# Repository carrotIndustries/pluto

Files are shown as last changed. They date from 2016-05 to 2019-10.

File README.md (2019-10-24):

Pluto is a programmable digital watch that re-uses case and LCD 
panel of the Casio® F-91W.  This is the hardware repo, for the 
software side of things, see [pluto-fw](https://github.com/carrotIndustries/pluto-fw).
Looking for pictures? [There you go.](photos/)
You can discuss the project and ask questions on the [EEVblog forum](http://www.eevblog.com/forum/oshw/diy-watch-based-on-the-casio-f-91w/)

# Features
- Displays time in decimal/binary/hexadecimal base
- Multiple alarms
- Multiple countdown timers
- Uses RTTTL ringtones for alarm sound
- Stopwatch
- Compass
- Speedometer (Enter distance, watch measures time and displays speed in km/h)
- Generation of time-based one-time passwords according to RFC 6238 (WIP)
- Menu-driven interface
- Infrared receiver for software updates and TOTP secret transfer (WIP)
- Useless customisation (Key beep frequency, etc.)
- greater than 1 year battery life (estimate based on current consumption)

# Hardware
Pluto replaces the PCB of the Casio F-91W with a custom one containing 
a MSP430FR6972 MCU, a digital magnetometer (compass) and a 38 kHz 
infrared receiver for software updates and communication. Due to 
careful planning and luck, the Pluto PCB perfectly fits inside of the 
F-91W's mounting frame, although it houses many more components.

- [Schematic as PDF](f-91w.pdf)
- [Kitspace page with BOM and links to buy the parts](https://kitspace.org/boards/github.com/carrotIndustries/pluto)
- [BOM](f-91w.bom)
- [Kitspace BOM](1-click-bom.csv)
- [BOM with Mouser and Digikey part numbers](bom_mouser_digikey.txt)

## MCU
The MSP430FR6972 is a low-power 16bit MCU with integrated segment LCD 
controller. It can be programmed and debugged using the two-wire 
SBW interface accessible through holes in the mounting frame. 

## Digital Magnetometer
The MAG3110 compass is connected to the MCU via I²C. To reduce its power 
consumption to zero when not in use, it's powered from GPIO pin. Due to 
layout constraints, the MCU's I²C interface can't be used, so the 
MCU's firmware has to implement a bit-banged I²C master controller.

## Infrared Receiver
The TSOP57338 38kHz IR receiver is powered from GPIO pin as well since 
it doesn't have any power saving modes. Transmitter and firmware 
support are WIP.

## Other components
The backlight LED is connected to two GPIO pins, so that LEDs of either 
orientation can be fitted.
The driving circuit for the buzzer uses an inductor (measured approx. 
10mH) to boost the battery voltage for increased volume.

## PCB
We manufactured the PCB at [elecrow](http://www.elecrow.com). PCB 
thickness has to be 0.6mm for the PCB to fit between battery clip and plastic 
frame. Note that the PCB has "castellated vias" (for contacting the 
button springs) as PCB manufacturers usually surcharge for these. We 
chose to use ENIG (gold) finish since the original PCB is gold-plated 
as well and Casio wouldn't have done so if this wasn't strictly 
necessary. Unfortunately, not all vias are covered with solder mask due 
manufacturing details (in the gerber files, they are), so you'll have 
to insulate the bottom side of the PCB from the battery with sticky 
tape.

# Software
For details on the software, see the software repository at 
[pluto-fw](https://github.com/carrotIndustries/pluto-fw).

# Why?
I used to own an ez430-Chronos watch, but after several years of use, 
the rubber wrist strap disintegrated, so I needed a new programmable watch. 
Pretty much all of the existing DIY watches are impractical for daily 
use because of bulk, being not waterproof or having miserable battery 
life. 

# PAQ (Possibly asked questions)
Q: Why not just use a smartwatch?  
A: Smartwatches have a miserable battery life of one week at best. Some 
even require user interaction to display the time.

Q: Why isn't there some sort of radio interface? (BLE, nRF24L01)  
A: Take look at [this](photos#perfect-fit) picture to get an idea of the space available 
inside of the F-91W frame. The nRF24L01 is 4 mm×4 mm and barely fits, but 
requires external components like balun and antenna. There's no space 
for these. An IR receiver is the same size as the nRF24L01, but doesn't 
require any external components. TI's CC430 MCUs seem like a perfect 
match for pluto as since they combine MCU and radio, but since the radio operates at 
sub-1GHz frequency, the antenna needs to be prohibitively large.

Q: Why is there no accelerometer?  
A: Accelerometers are the most useful when they're permanently active 
for applications like sleep trackers, pedometers or features like 
"shake to do something". Unfortunately, even accelerometers marketed as
"ultralow power" draw approx 30 µA when running, draining the CR2016
coin cell in less than half a year.  So we decided to dedicate the 
available space to a digital compass.

# Credits
Thanks go to [sh-ow](https://github.com/sh-ow) for adding the compass 
and helping to get the board ready for manufacturing.

# Mixed bag
Stuff loosely related to this project

## Reverse Engineering bare glass LCD panels
For basics on bare glass LCD panels and how to drive them,
see application notes from various MCU vendors.

For driving an unknown LCD panel, one needs to know which 
pins connect to the backplanes (COM) and which ones connect to segments 
(SEG). The easiest way to do so is to apply a square to all pins of the 
LCD panel and invert one pin at a time. When few segments light up, 
you've got a SEG pin, when many light up, you've got a COM pin. 
Sometimes apparently independent LCD segments are driven as one segment 
to save SEG pins. 

## Reverse engineering intricate PCB outlines
The F91-W's original PCB has a rather complicated outline that needs to 
be duplicated with high precision, so that the Pluto PCB fits nicely 
within the existing mounting frame.

By desoldering the spring contacting the piezo buzzer, the PCB is 
completely flat on the bottom side, so it can be placed on a flat-bed 
scanner. This eliminates any kind of distortion you'd get by taking a 
photo. The scanned image can then be scaled to match the actual 
dimensions measured with a caliper. There may be unequal scaling in X 
and Y direction due to inaccuracies of the scanner. We've now got a 
pretty accurate digital representation of the PCB that can be used for 
tracing out the outline and registering photos from the top side of 
the PCB to get the position of pads on top side.

Inkscape and GIMP (for correcting camera distortion) work well for 
these tasks. The resulting outline has been exported as a dxf document 
for importing the outline in KiCad.

## Things that didn't work out
The project started off with the intent of re-purposing the the F-91W 
case and LCD. Unfortunately, the LCD panel of the F-91W is rather 
limited since some LCD segments are driven as one segment.

So we went out and took a look at the Casio W800, F-201 and DB-36 
watch. After manufacturing a test jig for the LCD panels of the former 
two, it turned out that people at Casio /really/ like building LCDs 
with 5 backplanes. For some reason, the LCD panels need also to be driven 
with around 5 Vpp to achieve decent contrast. (Best guess: These 
watches are old designs, LCDs weren't that sensitive back then)

To my best knowledge, there's no (non-unobtainium) MCU on the market, 
that can boost a 3 V supply to 5 V for driving and LCDs /and/ can do 
5-mux. The only MCUs meeting the first requirement are from the RL78 
family from Renesas, but they only do 1,2,3,4 and 8-mux. Driving a 5-mux LCD 
with 8-mux waveforms leads to bad contrast. With 3 V and 5-mux, the contrast is 
much worse.

EPSON offers some obscure MCUs that can do both 5-mux and 
5 V LCD drive, but these ones don't have enough segment pins the QFN64 
package.

So we went back to F-91W.

## Measuring current consumption
For plotting current consumption over time, the EnergyTrace feature of 
the MSP430FR4133 LaunchPad has proven to be really useful: 
[energytrace-util](https://github.com/carrotIndustries/energytrace-util)

## Related Projects
Looking for more buttons and a radio? Take a look at [goodwatch](https://github.com/travisgoodspeed/goodwatch/)

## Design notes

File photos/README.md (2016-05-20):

People like photos, so I took some.

#Whole Watch
Pretty boring, looks just like every F-91W, apart from the binary time 
display.  Top vertical segments are hours, bottom vertical segments are 
minutes, horizontal segments are there for locating the bits.

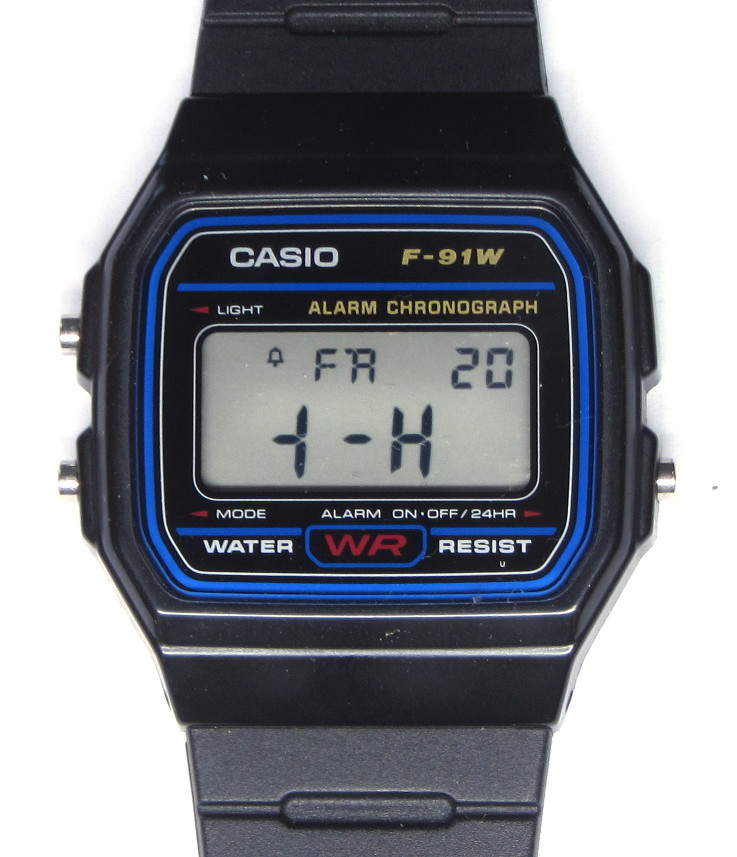
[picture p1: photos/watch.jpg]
Watch


#Frame
The wire sticking out of the bottom left hole is connected to Vcc. It 
has been used to power the watch during firmware development.

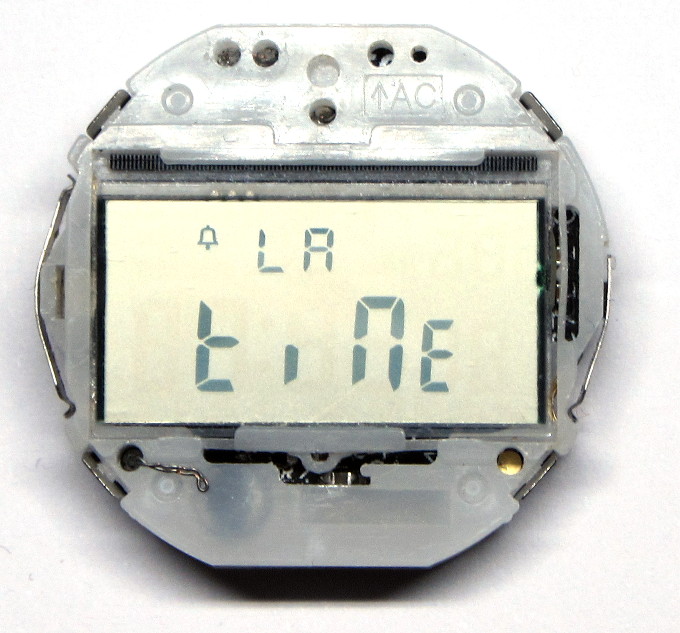
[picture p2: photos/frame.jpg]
Frame


#Populated PCB
Despite of the small-sized components (all passives are 0402),
populating the pluto PCB is doable given a microscope and plenty of 
flux. The inductor at the bottom left as been harvested from the 
original PCB. The crystal is wrapped in sticky tape to avoid shorting C1.

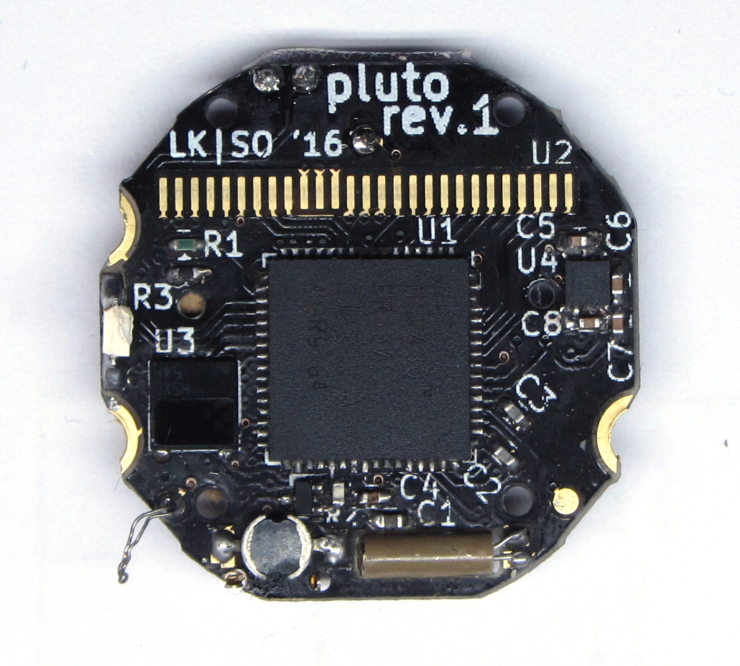
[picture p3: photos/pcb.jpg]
populated pcb


#Perfect fit
Like magic, all components fit perfectly within the plastic frame. 
Little space has been wasted.

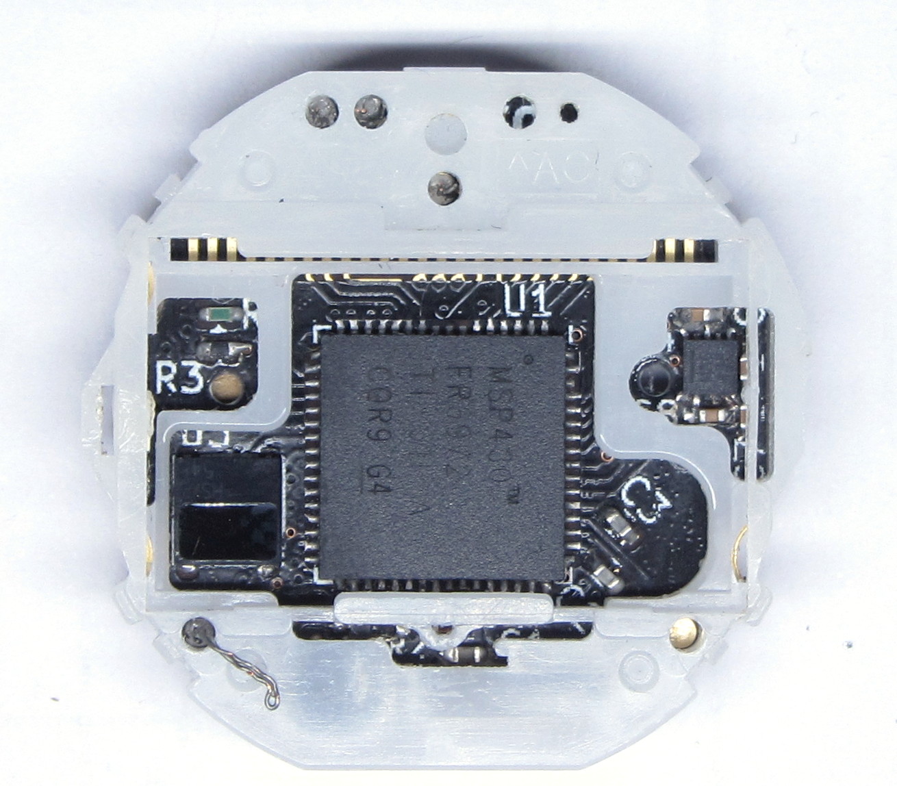
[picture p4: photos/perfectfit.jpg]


#Blank PCB
I case you're curios, there it is:

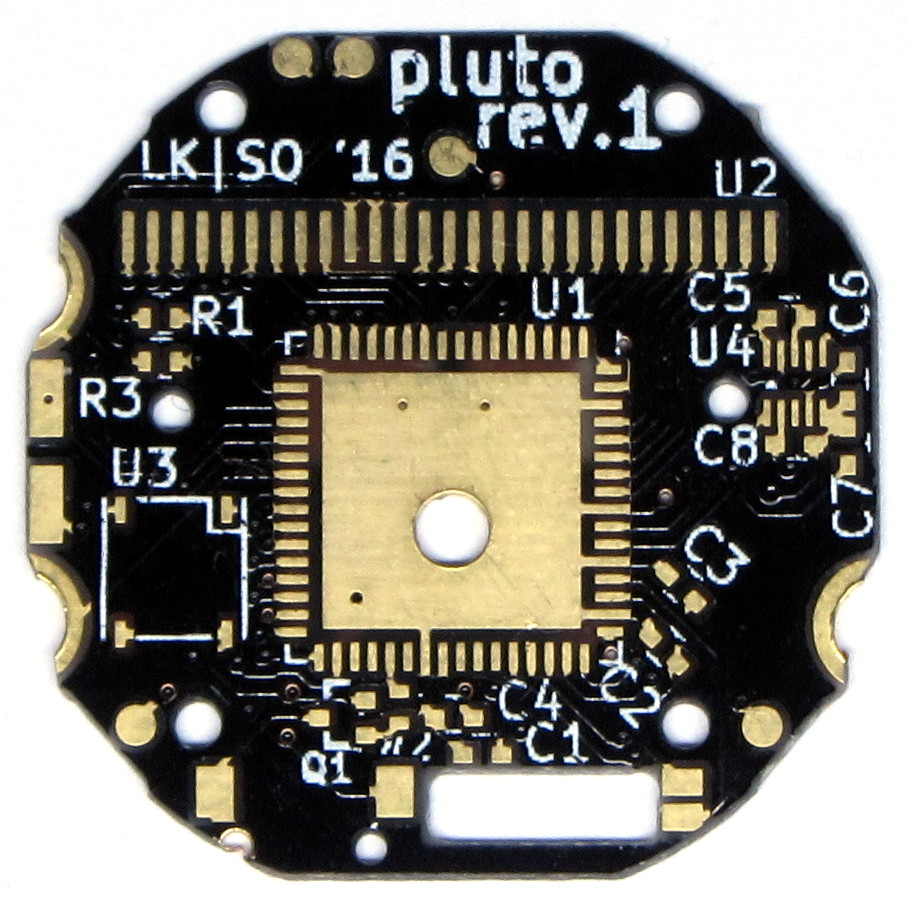
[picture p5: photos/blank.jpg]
blank pcb


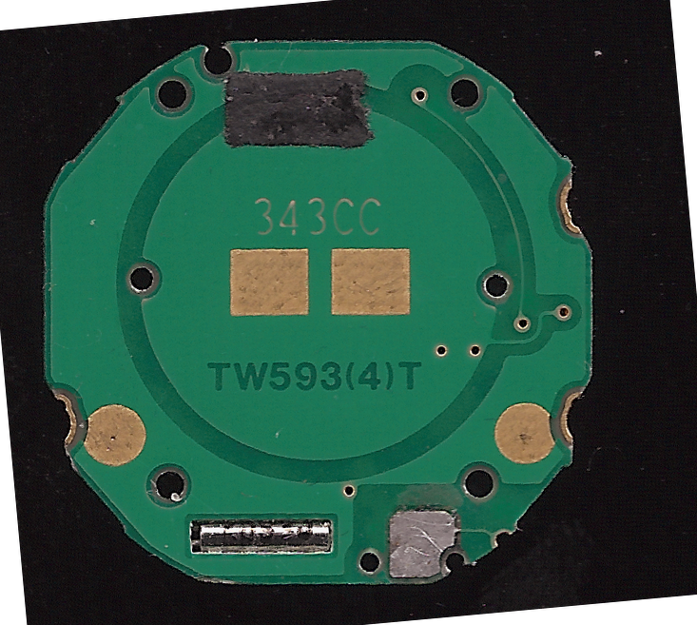
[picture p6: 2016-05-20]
mech/pcb.png

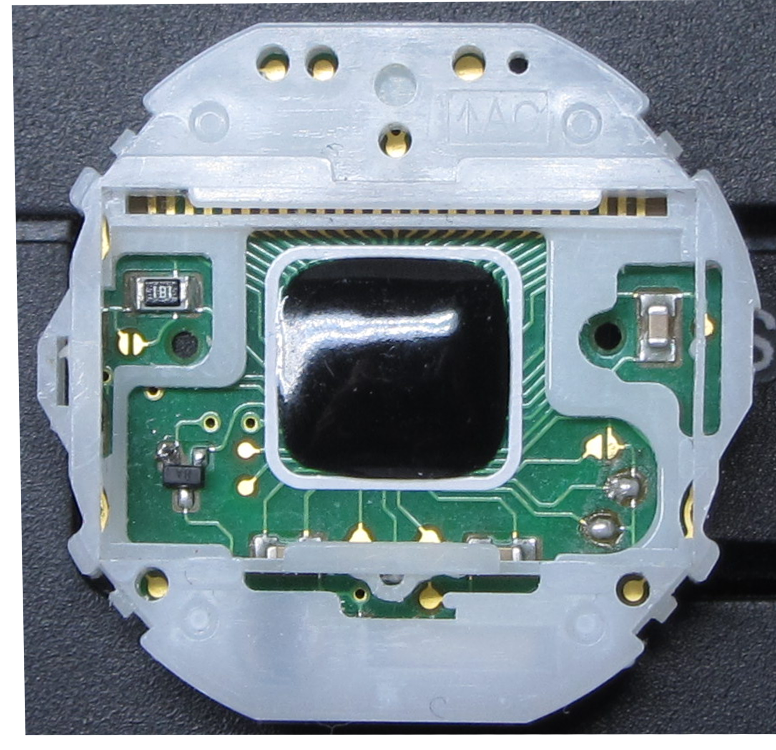
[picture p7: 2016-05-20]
mech/frame.png

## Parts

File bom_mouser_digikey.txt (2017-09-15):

Mouser
--------------------------------------------------------------------------------
QTY  Mouser Part No           MPN                   Description
1    71-CRCW0402100RFKEDH     CRCW0402100RFKEDHP    0402 1/8watt 100ohms 1%
2    810-C1005NP01H120J0A     C1005NP01H120J050BA   0402 12pF 50volts
1    720-LOY876Q2T124Z        LO Y876-Q2T1-24-Z     Orange, 606nm, side view
1    559-NC26-LF              NC26LF-327            32.768 KHz 2X6
5    810-C1005X7R1E104K       C1005X7R1E104K050BB   0402 100nF 10% 25Volts
1    841-MAG3110FCR1          MAG3110FCR1           XYZ DIGITAL SENSOR
1    78-TSOP57438TT1          TSOP57438TT1          IR SENSOR IC 38KHZ
1    594-MCS04020C4702FE0     MCS04020C4702FE000    0402 .063W 47Kohm 1%
1    71-TNPW040210K0DETD      TNPW040210K0DETD      0402 10Kohms .5% 25ppm
1    771-BC846BT115           BC846BT,115           SOT-416-3 TRANS GP TAPE-7
1    810-C1005X5R0J475K       C1005X5R0J475K050BC   0402 4.7uF 6.3volts
1    595-430FR6972IRGCR       MSP430FR6972IRGCR     16-bit Microcontroller (TI)

Digikey
--------------------------------------------------------------------------------
QTY  Digikey Part No          MPN                   Description
1    541-2910-1-ND            RCS0402100RJNED 	    0402 100 OHM 5% 1/5W
2    445-13786-1-ND           C1005NP01H120J050BA   0402 12pF 50volts
1    475-1167-1-ND            LO Y876-R2T1-24-Z     Orange, 606nm, side view
1    631-1205-ND              NC26LF-327            32.768 KHz 2X6
5    445-7348-2-ND            C1005X7R1E104K050BB   0402 100nF 10% 25Volts
1    MAG3110FCR1CT-ND         MAG3110FCR1           XYZ DIGITAL SENSOR
1    TSOP57438TT1CT-ND        TSOP57438TT1          IR SENSOR IC 38KHZ
1    541-47.0KLCT-ND          CRCW040247K0FKED 	 	0402 47K OHM 1% 1/16W
1    541-10.0KLCT-ND          CRCW040210K0FKED      0402 10K OHM 1% 1/16W
1    BC847BTT1GOSCT-ND        BC847BTT1G 	        TRANS NPN 45V 0.1A SC75-3
1    445-5947-1-ND            C1005X5R0J475K050BC   0402 4.7uF 6.3volts
1    296-42269-1-ND           MSP430FR6972IRGCR     16-bit Microcontroller (TI)

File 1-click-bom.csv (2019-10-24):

References | Qty | Description | Manufacturer | MPN | Manufacturer | MPN | Manufacturer | MPN | Digikey | Mouser | RS | Newark | Farnell
Q1 | 1 | SOT416 BC846 | ON Semiconductor | BC847BTT1G |  |  |  |  | BC847BTT1GOSDKR-ND | 863BC847BTT1G | 8009614P |  | 2464041
U2 | 1 | LCD-F-91W
C2, C3 | 2 | Capacitor SMD 0402 22pF | KEMET | C0603C180J5GAC TU. | KEMET | C0603C180J5GACTU | Yageo | CC0402JRNPO9BN220 | 311-1018-6-ND | 603CC402JRNPO9BN220 | 1699965 |  | 3019184
C8, C4, C5, C6, C7 | 5 | Capacitor SMD 0402 100nF | KEMET | C0603C104K5RACTU | TDK | C1005X7R1E104K050BB | Murata | GRM155R71C104KA88D | 490-3261-1-ND | 81GRM155R71C104KA88 | 6242317 |  | 2525045
C1 | 1 | Capacitor SMD 0402 4.7uF | TDK | C1005X5R0J475K050BC |  |  |  |  | 445-5947-1-ND | 810C1005X5R0J475K | 7882821 |  | 2346876
U1 | 1 | 16-bit Microcontroller (TI) | Texas Instruments | MSP430FR6972IRGCR |  |  |  |  | 296-49839-1-ND | 595430FR6972IRGCR
R2 | 1 | Resistor SMD 0402 47k | Yageo | RC0402FR-0747KL |  |  |  |  | 311-47.0KLRDKR-ND | 603RC0402FR0747KL |  |  | 2459293
R1, R3 | 2 | Resistor SMD 0402 10k | Vishay | CRCW040210K0FKED | Panasonic | ERJ-2RKF1002X | Yageo | RC0402FR-0710KL | 311-10.0KLRCT-ND | 603RC0402FR0710KL | 1067096 |  | 2144755
U3 | 1 | TSOP57xxx TSOP57xxx | Vishay | TSOP57438TT1 |  |  |  |  | TSOP57438TT1CT-ND | 78TSOP57438TT1 |  |  | 2251385
U4 | 1 |  | NXP Semiconductors | MAG3110FCR1 |  |  |  |  |  |  |  |  | 2080492

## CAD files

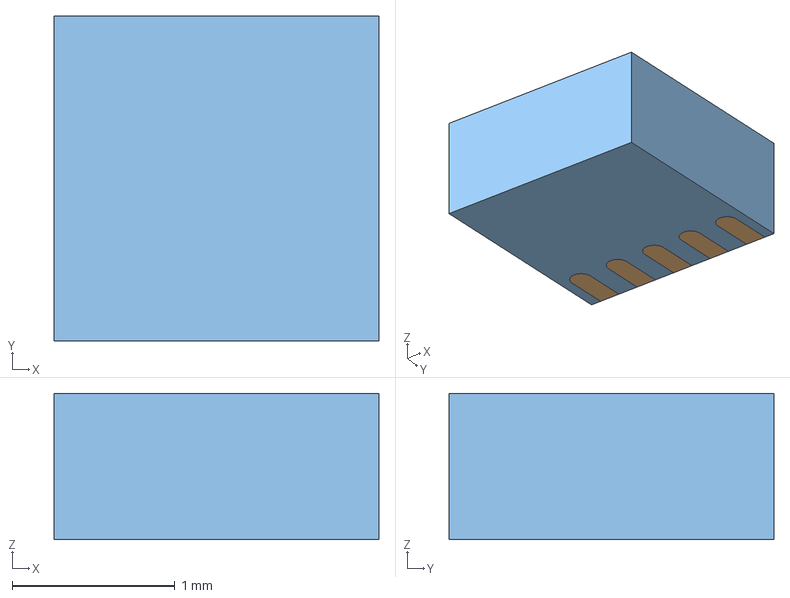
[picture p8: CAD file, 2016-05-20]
10-pin_DFN/10-pin_2x2mm_DFN10.fcstd
2.00 x 2.00 x 0.9 mm
Array (Mirror #1)

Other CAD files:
10-pin_DFN/10-pin_2x2mm_DFN10.obj

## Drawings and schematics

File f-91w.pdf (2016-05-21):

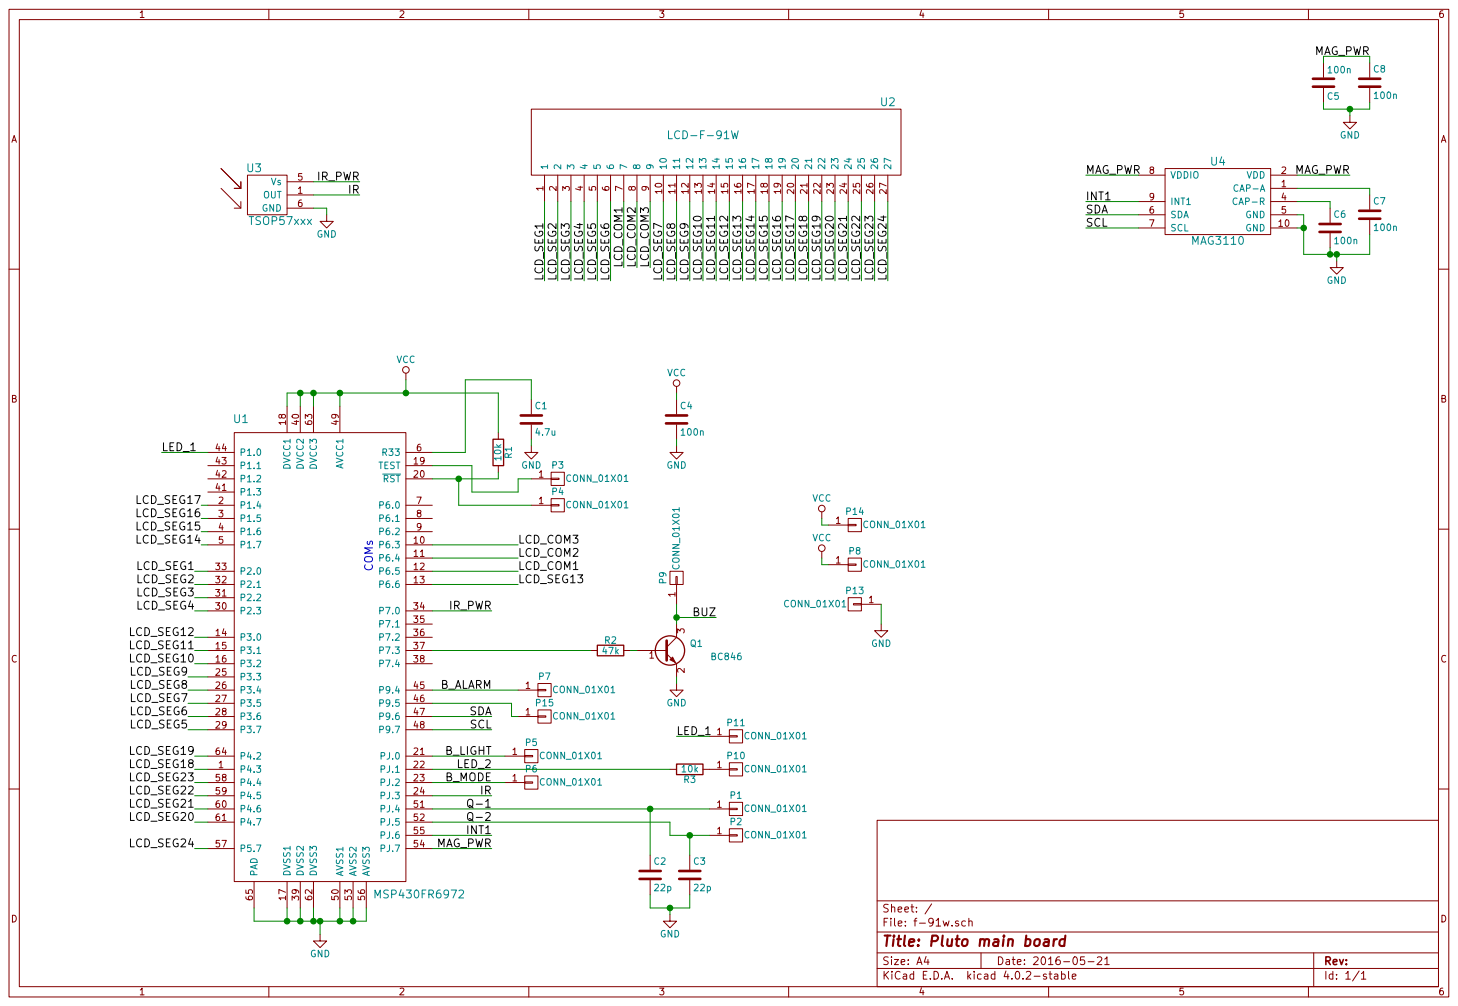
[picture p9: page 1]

INT1 MAG_PWR

Id: 1/1 Title: Pluto main board

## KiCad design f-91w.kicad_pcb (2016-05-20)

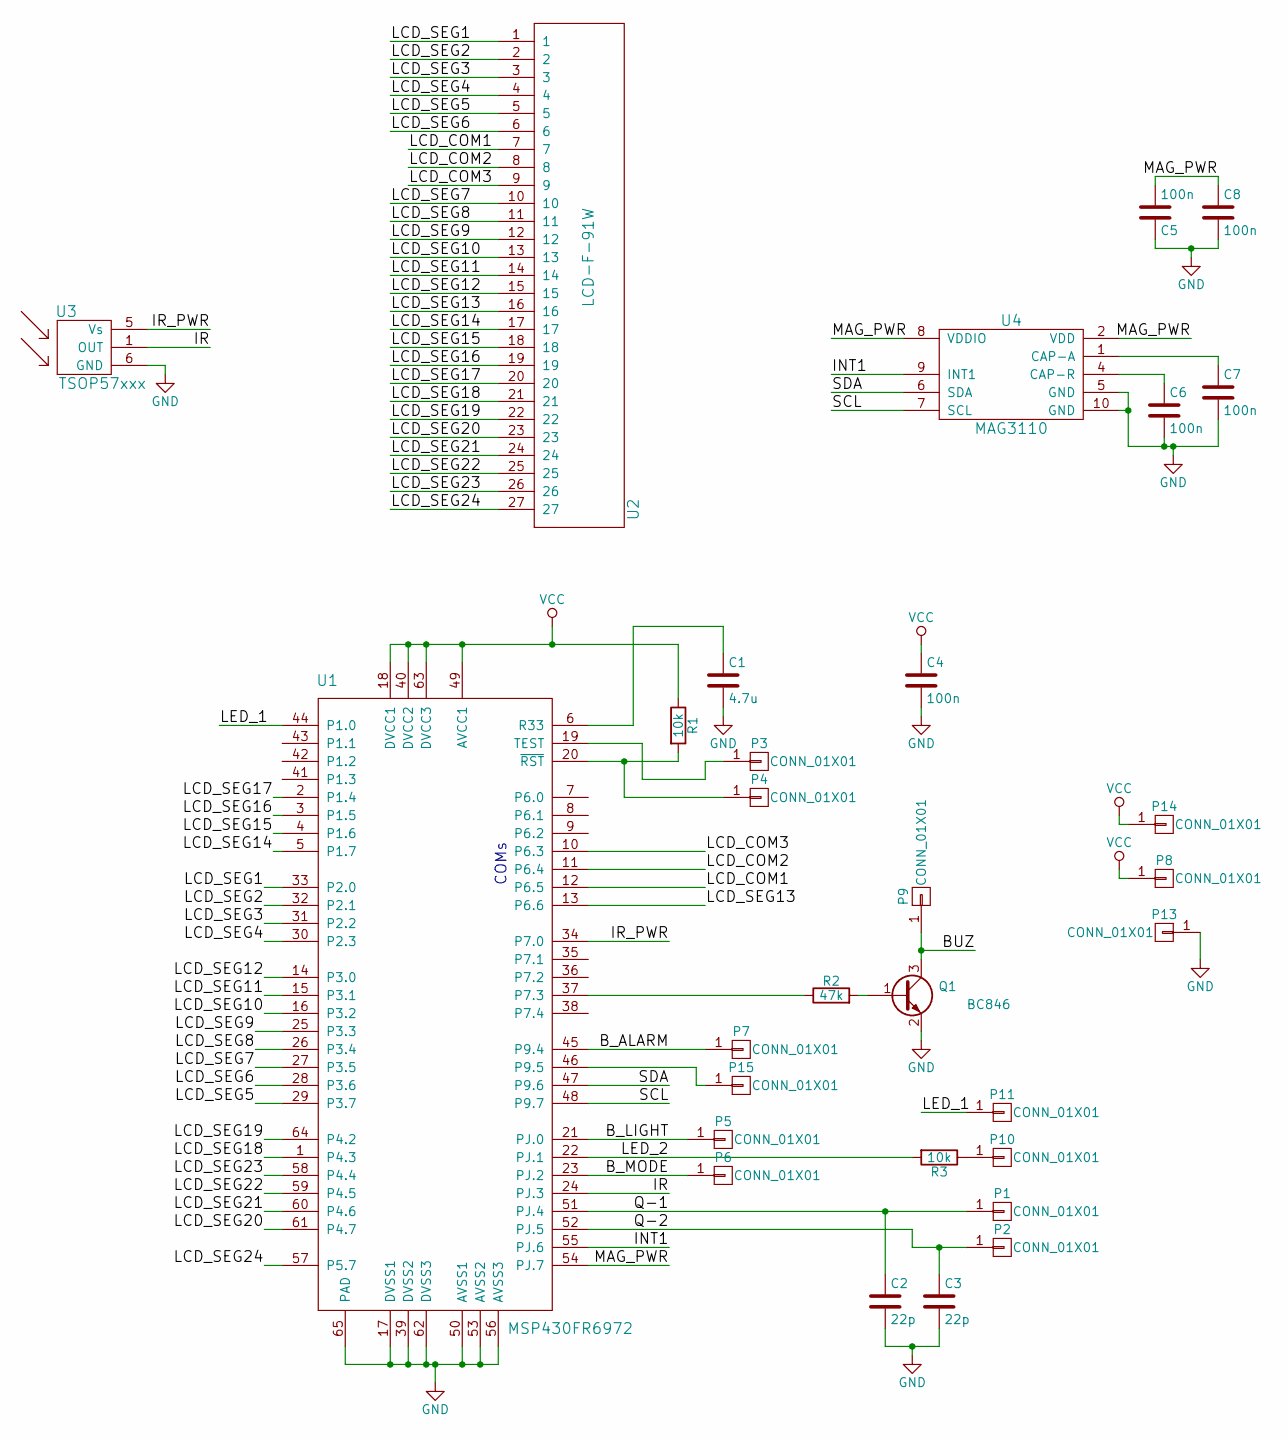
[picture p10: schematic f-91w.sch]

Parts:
C1: 4.7u; C_0402
C2, C3: 22p; C_0402
C4, C5, C6, C7, C8: 100n; C_0402
P1, P2, P3, P4, P5, P6, P7, P8, P9, P10, P11, P13, P14, P15: CONN_01X01; 1pin
Q1: BC846; SOT416
R1, R3: 10k; R_0402
R2: 47k; R_0402
U1: MSP430FR6972; QFN-64-1EP_9x9mm_Pitch0.5mm
U2: LCD-F-91W
U3: TSOP57xxx
U4: MAG3110; DFN-10-1EP_2x2mm_Pitch0.4mm

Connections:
/BUZ: P9.1, Q1.3 (C)
/B_ALARM: P7.1, U1.45 (P9.4)
/B_LIGHT: P5.1, U1.21 (PJ.0)
/B_MODE: P6.1, U1.23 (PJ.2)
/INT1: U1.55 (PJ.6), U4.9 (INT1)
/IR: U1.24 (PJ.3), U3.1 (OUT)
/IR_PWR: U1.34 (P7.0), U3.5 (Vs)
/LCD_COM1: U1.12 (P6.5), U2.7
/LCD_COM2: U1.11 (P6.4), U2.8
/LCD_COM3: U1.10 (P6.3), U2.9
/LCD_SEG1: U1.33 (P2.0), U2.1
/LCD_SEG2: U1.32 (P2.1), U2.2
/LCD_SEG3: U1.31 (P2.2), U2.3
/LCD_SEG4: U1.30 (P2.3), U2.4
/LCD_SEG5: U1.29 (P3.7), U2.5
/LCD_SEG6: U1.28 (P3.6), U2.6
/LCD_SEG7: U1.27 (P3.5), U2.10
/LCD_SEG8: U1.26 (P3.4), U2.11
/LCD_SEG9: U1.25 (P3.3), U2.12
/LCD_SEG10: U1.16 (P3.2), U2.13
/LCD_SEG11: U1.15 (P3.1), U2.14
/LCD_SEG12: U1.14 (P3.0), U2.15
/LCD_SEG13: U1.13 (P6.6), U2.16
/LCD_SEG14: U1.5 (P1.7), U2.17
/LCD_SEG15: U1.4 (P1.6), U2.18
/LCD_SEG16: U1.3 (P1.5), U2.19
/LCD_SEG17: U1.2 (P1.4), U2.20
/LCD_SEG18: U1.1 (P4.3), U2.21
/LCD_SEG19: U1.64 (P4.2), U2.22
/LCD_SEG20: U1.61 (P4.7), U2.23
/LCD_SEG21: U1.60 (P4.6), U2.24
/LCD_SEG22: U1.59 (P4.5), U2.25
/LCD_SEG23: U1.58 (P4.4), U2.26
/LCD_SEG24: U1.57 (P5.7), U2.27
/LED_1: P11.1, U1.44 (P1.0)
/LED_2: R3.2, U1.22 (PJ.1)
/MAG_PWR: C5.2, C8.1, U1.54 (PJ.7), U4.2 (VDD), U4.8 (VDDIO)
/Q-1: C2.1, P1.1, U1.51 (PJ.4)
/Q-2: C3.1, P2.1, U1.52 (PJ.5)
/SCL: U1.48 (P9.7), U4.7 (SCL)
/SDA: U1.47 (P9.6), U4.6 (SDA)
GND: C1.2, C2.2, C3.2, C4.2, C5.1, C6.2, C7.2, C8.2, P13.1, Q1.2 (E), U1.17 (DVSS1), U1.39 (DVSS2), U1.50 (AVSS1), U1.53 (AVSS2), U1.56 (AVSS3), U1.62 (DVSS3), U1.65 (PAD), U3.6 (GND), U4.5 (GND), U4.10 (GND)
unnamed: C1.1, U1.6 (R33)
unnamed: C6.1, U4.4 (CAP-R)
unnamed: C7.1, U4.1 (CAP-A)
unnamed: P3.1, U1.19 (TEST)
unnamed: P4.1, R1.2, U1.20 (~RST)
unnamed: P10.1, R3.1
unnamed: P15.1, U1.46 (P9.5)
unnamed: Q1.1 (B), R2.2
unnamed: R2.1, U1.37 (P7.3)
VCC: C4.1, P8.1, P14.1, R1.1, U1.18 (DVCC1), U1.40 (DVCC2), U1.49 (AVCC1), U1.63 (DVCC3)

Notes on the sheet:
COMs

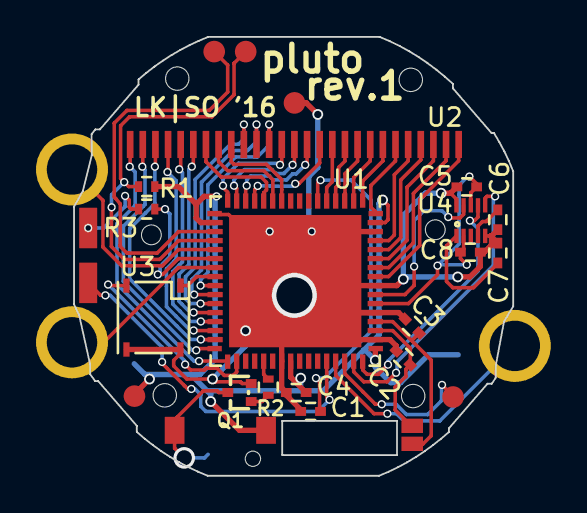
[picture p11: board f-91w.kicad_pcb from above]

Board: 2 copper layers, 24.4 x 24.4 mm, 37 parts (0 on the bottom side), 52 nets.

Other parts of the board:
MH1, MH2, MH3, MH4, MH5, MH6, MH7: 1pin

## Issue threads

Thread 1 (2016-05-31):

buy populated PCBs?

hackrid, 2016-05-31:
Hi,

is there a way to buy populated PCBs ?

BR

luftek, 2017-12-27:
Probably not relevant any more? I did order new batch? #11

vasev01, 2018-10-16:
I’m also interested in buying one populated PCB.

carrotIndustries, 2018-10-18:
Don't hold your breath, but I might to a second board cut in the next few months. Stay tuned!

carrotIndustries, 2018-10-18:
Yeah, that's why I was planning on removing the magnetometer in the next revision. It's been more of a gimmick anyhow.

vasev01, 2019-10-24:
@carrotIndustries A year has passed since you announced a second board in few months. I'm wearing the original casio all the time hoping to be able to program it. Any positive news?

smaslennikov, 2019-10-24:
I, too, am still holding my breath.

carrotIndustries, 2019-10-24:
I'm really sorry, but I'm too busy with other projects to get a new pluto revision out the door.

Anyhow, this project is open source hardware, so feel free to organize make a new rev on your own.

If I'd do it, I'd change these things:
 - Drop compass (EOL and not that useful after all) and IR sensor (no firmware support)
 - Panelize the PCB to drive cost down
 - Make the Vcc capacitor 1µF

If someone really wants to pull this off, I can do design support and review on a best-effort basis.

Good luck!

wannessels, 2019-10-26:
Could you have a look at my [pull request](https://github.com/carrotIndustries/pluto/pull/6)? I'd like to order a batch of boards

tandy-1000, 2020-11-23:
im also interested in this

wannessels, 2020-11-30:
I'll have a go at ordering new PCB's.

Anyone who's interested, can you tell me what and how many you're interested in?
- Bare PCB's
- PCB + components, unsoldered. You will need some sort of MSP430 devkit to flash the mcu
- PCB + components, soldered and flashed. You will still need to desolder and reuse the inductor from a donor F-91W

vasev01, 2020-11-30:
@wannessels, the bare PCB is not a problem nowadays just drop a zip file with gerbers and fill in your address and you are done. However, soldering small SMD components, especially those VQFNs and BGAs, is the problem for many of us.
So, my choice would be PCB with soldered components (at least CPU).

Thanks,
Eugene.

lpasselin, 2020-11-30:
How much would that be total for each popupated PCB including parts?

smaslennikov, 2020-11-30:
Depending on pricing, I'd go for somewhere between two and five populated boards.

tandy-1000, 2020-11-30:
id be interested in one populated board

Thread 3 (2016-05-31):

why no sub-optimal 1 GHz antenna?

hackrid, 2016-05-31:
even if no long distances could be reached, wouldn't this be a good feature?

it would also free up board space for a barometric pressure sensor. the watch housing is not hermetic which should make pressure sensing inside the housing possible. not ?

carrotIndustries, 2016-05-31:
I guess you're thinking of the the CC430 MCUs? We've thought of them as well, but couldn't find a suitable antenna. Since I've got no experience in designing antennas, the only choice would have been a chip antenna. All of these were way too large to fit inside the plastic frame. Aside from the antenna, the RF part requires an extra crystal, extensive decoupling and a balun.

The ez430 Chronos at least has a special rubber dome above the pressure sensor, so I guessed that a pressure sensor doesn't work through the rubber seal on the back of the watch.

hackrid, 2016-06-01:
your right, the crystal and the balun might be a show stopper.

I'm no RF expert, but even a really bad antenna design might work for a few meters.

the ez430 Chronos is "30m water resistant" which makes it more hermetic and thus might need a membrane for the pressure sensor.

hackrid, 2016-06-02:
what are your thoughts regarding NFC?

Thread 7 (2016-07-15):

Vibration/Haptic Feedback

nigelcm, 2016-07-15:
How much current would a small vibration motor draw from the coin cell?
I am super interested in an f91w that has a vibrate alarm.

carrotIndustries, 2016-07-15:
The current draw shouldn't be the problem since the vibration motor would only be active for brief amounts of time. But take a look at this photo: https://github.com/carrotIndustries/pluto/tree/master/photos#perfect-fit There really is no space for any kind of vibration motor.

nigelcm, 2016-07-15:
I wonder if a modified backplate could allow for more room? It kind of defeats the initial purpose of the project though.

ixt, 2016-11-15:
perhaps a piezoelectric actuator could provide this? they can be purchased relatively small

lpasselin, 2017-03-16:
Would it be possible to completely remove the LCD and related components to place the vibration motor?

The readme mentions you tried the W800 watch when testing for the LCD. The W800 is 5mm thicker than the f91. Do you think it would be possible to fit everything in the W800 (possibly also removing the LCD)?

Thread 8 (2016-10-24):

Thermometer/pressure sensor

JIFFNET, 2016-10-24:
I was wondering if it was possible to squeeze inside a tiny smd thermistor or even a pressure sensor. It would be a perfect match with digital compass.

carrotIndustries, 2016-10-25:
The compass already contains a thermometer, though that one needs to be calibrated since it has some significant offset.

I don't think that an extra pressure sensor fits within the existing frame without dropping the compass/IR receiver. If you really want the pressure sensor, I'd recommend rolling your own PCB with the compass/IR receiver replaced by a pressure sensor. When modifying the PCB, make sure all components still fit within the mounting frame.

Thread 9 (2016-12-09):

BOM mismatch

wannessels, 2016-12-09:
Q1 is missing in bom_mouser.txt . Something like [771-BC846BW-T/R](http://www.mouser.be/ProductDetail/NXP-Semiconductors/BC846BW115/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)?
LED1 is missing in f-91w.bom
C2 & C3 are 22pF in f-91w.bom, but 12pF in bom_mouser.txt

Can you recommend an inductor? I'd rather get a new one instead of the one from the stock f91w board.

wannessels, 2016-12-09:
Oh, and C2 & C3 are 22pF in f-91w.bom, but 12pF in bom_mouser.txt

carrotIndustries, 2016-12-11:
Uh, Q1 is in the bom: https://github.com/carrotIndustries/pluto/blob/master/bom_mouser.txt#L10 looks like it's obsolete, the one you mentioned looks fine. The exact type isn't that critical, it should have a Vce max of approx 60V and the right package.

Btw, feel free to experiment with the LED, with the one in the BOM the backlight isn't very uniform.

The load capacitors for the crystal should be 12pf as per the crystal's datasheet.

I've been looking for an inductor but haven't been able to find a replacement (10mH) that comes close. To make things harder, there's a cavity in the frame that is shaped to accommodate the stock inductor. Since you need to transplant the spring for contacting the piezo buzzer anyhow, transplanting the inductor as well didn't seem a hassle too big.

wannessels, 2016-12-11:
Ah, I copy pasted the BOM and when I didn't get the transistor I wrongfully assumed it was not in the bom. I probably ignored a warning from mouser when importing the txt.

The original watch already has lousy backlight (more like sidelight actually), so I don't think this can be fixed, but I will try a few different leds.

luftek, 2017-12-27:
@wannessels  hi, did you make your own? kind regards

Closed 2017-12-27.

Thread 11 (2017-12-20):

Castellated holes, workaround

luftek, 2017-12-20:
Thank you for sharing you design files!
Files were not accepted by "my" PCB Fab so I sent them gerbers where EdgeCuts has some small ears.
Will share if and how goes through
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

luftek, 2017-12-29:
It went through fine. Cutting 0.6mm material is easy
Don't know how long HASL contacts for buttons will last? ENIG would be better

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

luftek, 2017-12-29:
Should I create a pull request for different branch or on the master branch?
It seems this option is cheaper compared to castellated holes although overall size did increase slightly

carrotIndustries, 2017-12-29:
Great hack to work around silly PCB fabs! A different branch would be the best place for this.

luftek, 2017-12-29:
https://github.com/luftek/pluto/commit/705c0e43f033279aaf257b78690a6cdfd135f872
Currently I am able to post a pull request only to master branch.
Please create second branch in your repo

Closed 2018-08-04.

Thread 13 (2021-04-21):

Does this MCU work?

modelkayak, 2021-04-21:
I was looking for an ARM based MCU to replace the TI MSP430.  I'm assuming the main design constraint is the LCD voltage needs to be at 5V.  As of April 2021, I noticed that NXP Kinetics line appears to be able to generate the 5V signal.

* K30 - https://www.nxp.com/docs/en/reference-manual/K30P64M72SF1RM.pdf
* K40 - https://www.nxp.com/docs/en/reference-manual/K40P64M72SF1RM.pdf

Would you agree that these MCUs would appear to work for this project?  Thanks!

(Note: I wonder if the M0[+] line would be more power efficient, but they don't call out 5V support https://www.nxp.com/docs/en/reference-manual/KL33P64M48SF6RM.pdf)

carrotIndustries, 2021-04-21:
> I'm assuming the main design constraint is the LCD voltage needs to be at 5V

The F-91W LCD glass works fine with 3V drive level, the MSP430 MCU doesn't support 5V LCD drive either.

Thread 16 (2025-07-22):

Pluto BOM and PnP files

kazz2020, 2025-07-22:
Is there a chance for BOm and PnP for JLCPCB for newst pcb for this?

carrotIndustries, 2025-07-22:
Nope, this project is done for me.

carrotIndustries, 2025-07-23:
I don't have the spoons for touching the project right now. I don't see why you couldn't do this yourself or ask someone else who knows where to click in KiCad for help.

Closed 2025-07-23.

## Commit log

2016-05-21 beautify schematic, add pdf
    [f-91w.sch]
2016-05-21 fix schematic link typo
2016-05-23 add bom
2016-05-23 readable bom, fix R3 val in schematic, add mouser order list
    [f-91w.sch]
2016-05-24 add PCB section to README, link in BOMs
2016-05-24 fix BOM links
2017-09-15 add digikey bom
2019-10-24 Make compatible with kitspace.org (#12)
    * Make compatible with kitspace.org
    * Add/fix links in readme
    [1-click-bom.csv]
